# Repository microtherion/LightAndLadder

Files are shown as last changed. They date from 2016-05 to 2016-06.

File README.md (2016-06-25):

[KiCad](http://kicad-pcb.org) design of simple testbench for microcontrollers.

The resistor networks should be pairwise identical; I've used 680Ω for the LED resistors, with 
blue & green LEDs (note that the LEDs are connected to the closest pin, so top and bottom row are 
each connected to **both** resistor networks), and 1kΩ for the ladder resistors. 

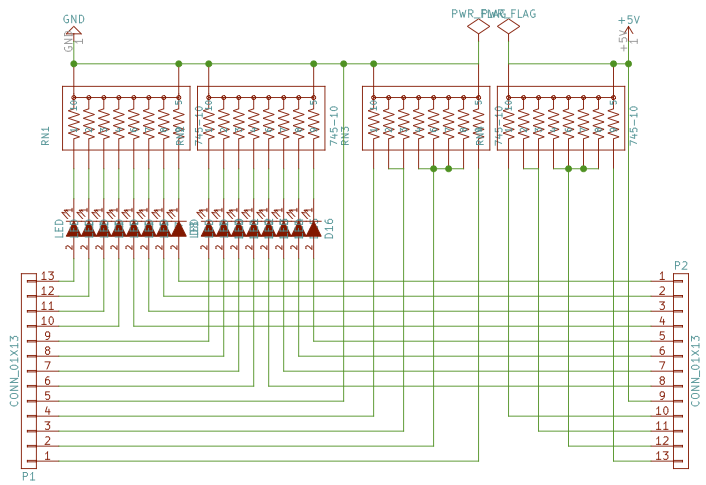
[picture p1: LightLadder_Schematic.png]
Schematic


So what is the "ladder" part good for? It's the world's most primitive analog computer, 
a.k.a a voltage divider that can be used to generate a wide 
range of fractions of VCC, according to the formula printed on the board:

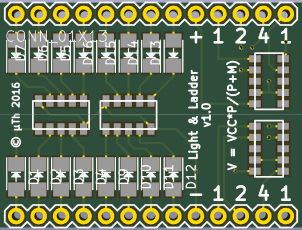
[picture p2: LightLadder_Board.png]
3D View


To generate a particular voltage, connect your analog input pin to one or several of the pins 
in the top row (next to the `+`) and one or several in the bottom row (next to `-`).

If VCC (applied to the `+` pin) is 5V, then

* `+1` / `-1` will generate `5V * (1 / (1+1)) = 2.5V` (as will `+2` / `-2` or `+4` / `-4`).
* `+1` / `-2` will generate `5V * (1 / (1+2)) = 1.6V`.
* `+2` / `-1` will generate `5V * (2 / (2+1)) = 3.2V`.
* `+1` / `-1,-2` will generate `5V * (1 / 1+1+2) = 1.25V`.

PCB available at [OSH Park](https://oshpark.com/projects/oy5yst8f)

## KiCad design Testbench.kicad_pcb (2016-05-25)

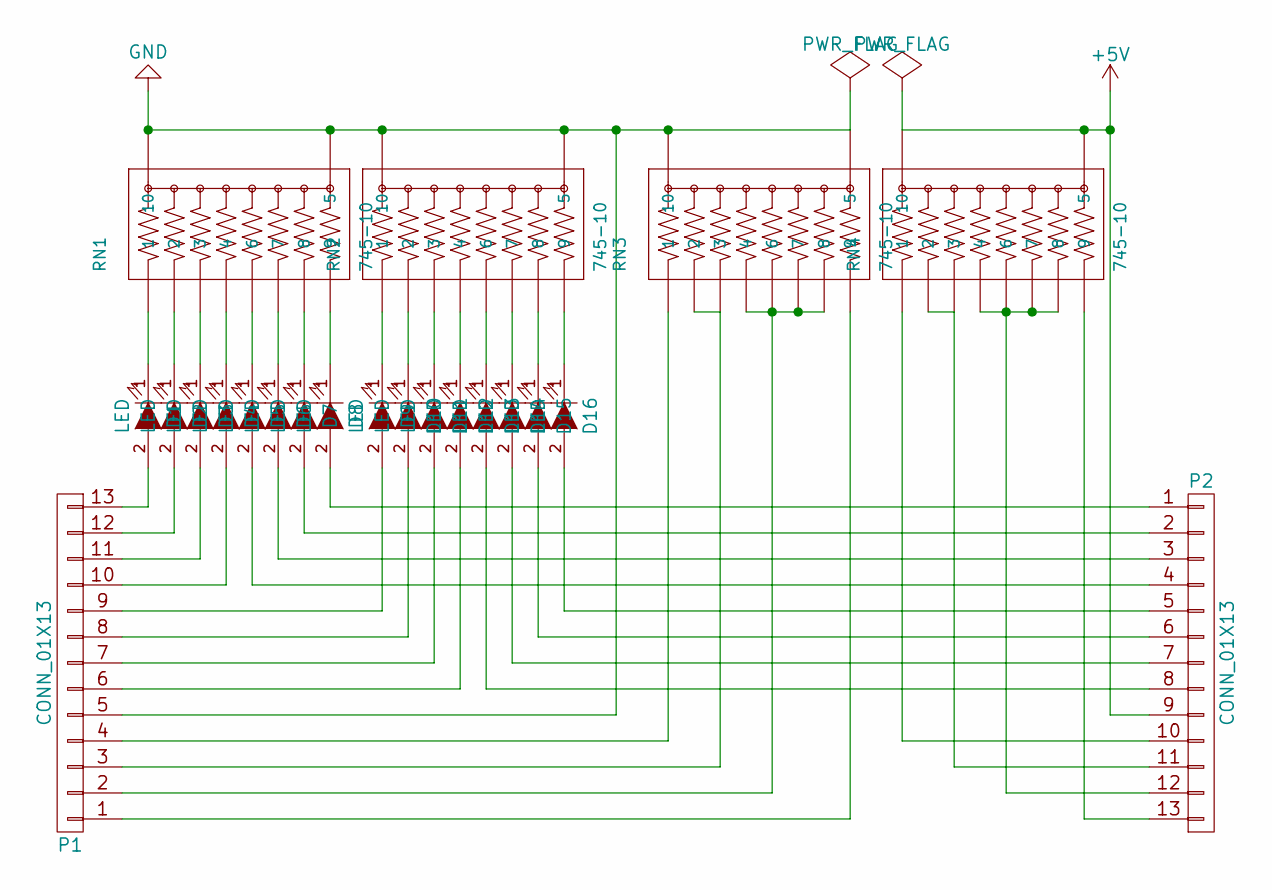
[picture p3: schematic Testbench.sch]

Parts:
D1, D2, D3, D4, D5, D6, D7, D8, D9, D10, D11, D12, D13, D14, D15, D16: LED; LED-1206
P1, P2: CONN_01X13; Socket_Strip_Straight_1x13
RN1, RN2, RN3, RN4: 745-10; resistor-array-745-10

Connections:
+5V: P2.9, RN4.5, RN4.10
GND: P1.5, RN1.5, RN1.10, RN2.5, RN2.10, RN3.5, RN3.10
unnamed: D1.1 (K), RN1.1
unnamed: D1.2 (A), P1.13
unnamed: D2.1 (K), RN1.2
unnamed: D2.2 (A), P1.12
unnamed: D3.1 (K), RN1.3
unnamed: D3.2 (A), P1.11
unnamed: D4.1 (K), RN1.4
unnamed: D4.2 (A), P1.10
unnamed: D5.1 (K), RN1.6
unnamed: D5.2 (A), P2.4
unnamed: D6.1 (K), RN1.7
unnamed: D6.2 (A), P2.3
unnamed: D7.1 (K), RN1.8
unnamed: D7.2 (A), P2.2
unnamed: D8.1 (K), RN1.9
unnamed: D8.2 (A), P2.1
unnamed: D9.1 (K), RN2.1
unnamed: D9.2 (A), P1.9
unnamed: D10.1 (K), RN2.2
unnamed: D10.2 (A), P1.8
unnamed: D11.1 (K), RN2.3
unnamed: D11.2 (A), P1.7
unnamed: D12.1 (K), RN2.4
unnamed: D12.2 (A), P1.6
unnamed: D13.1 (K), RN2.6
unnamed: D13.2 (A), P2.8
unnamed: D14.1 (K), RN2.7
unnamed: D14.2 (A), P2.7
unnamed: D15.1 (K), RN2.8
unnamed: D15.2 (A), P2.6
unnamed: D16.1 (K), RN2.9
unnamed: D16.2 (A), P2.5
unnamed: P1.1, RN3.9
unnamed: P1.2, RN3.4, RN3.6, RN3.7, RN3.8
unnamed: P1.3, RN3.2, RN3.3
unnamed: P1.4, RN3.1
unnamed: P2.10, RN4.1
unnamed: P2.11, RN4.2, RN4.3
unnamed: P2.12, RN4.4, RN4.6, RN4.7, RN4.8
unnamed: P2.13, RN4.9

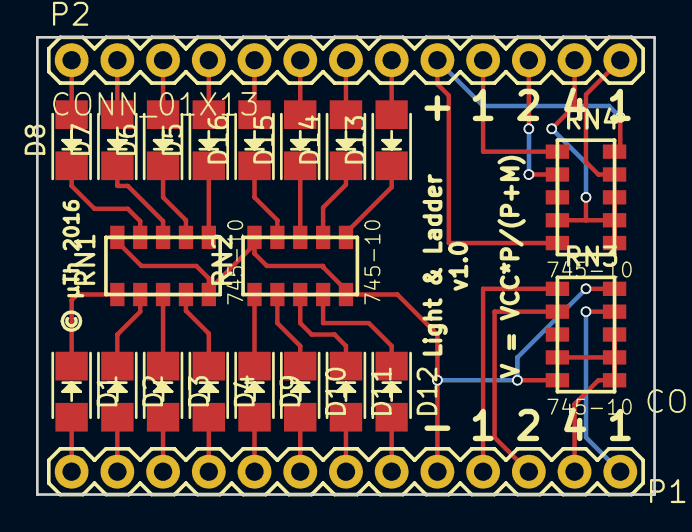
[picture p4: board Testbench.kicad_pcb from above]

Board: 2 copper layers, 34.3 x 25.4 mm, 22 parts (0 on the bottom side), 42 nets.
